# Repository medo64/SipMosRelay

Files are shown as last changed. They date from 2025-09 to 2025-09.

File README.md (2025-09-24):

SIP MOS Relay
-------------

High-voltage MOSFET-based switch in PhotoMOS footprint.

| Parameter | Min | Nom | Max |
|---|---:|---:|---:|
| Load voltage | 8 V | | 60 V |
| Continous load current | | | 6 A |
| Peak load current | | | 11 A |
| Power dissipation | | | 2 W |
| On-resistance | | 11.2 mΩ | 14.3 mΩ |
| Control input current  | |  500 µA | |
| Control current | | | 2 mA |
| Thermal resistance | | | 89.2 °C/W |
| Operating temperature  |  -40 °C | | +85 °C |

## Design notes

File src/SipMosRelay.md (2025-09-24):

## AuxPower Hardware

### Properties

| | |
|---|---|
| Size | 20.2 x 10.0 mm ~ 0.4 sqin |

### Parts

|  # | Part name | RefDes | Source |
|---:|---|---|---|
|  1 | D Zener 12V 0.5W [BZT52C12] (SOD123F) | D1 | 4878-BZT52C12DKR-ND |
|  1 | J Header (2w) | J1 | |
|  1 | J Header (3w) | J2 | |
|  1 | Q Transistor NPN 100 mA 65V [BC846B,235] (SOT23-3) | Q1 | 1727-1876-1-ND |
|  1 | Q MOSFET P 11A 60V ±20Vgs [RS3L110ATTB1] (SO-8) | Q2 | 846-RS3L110ATTB1CT-ND |
|  1 | R 10K 0.125W (0805) | R1 | RMCF0805FT10K0CT-ND |
|  2 | R 33K 0.125W (0805) | R2 | RMCF0805FT33K0CT-ND |
|  3 | R 47K 0.125W (0805) | R3 | RMCF0805FT47K0CT-ND |

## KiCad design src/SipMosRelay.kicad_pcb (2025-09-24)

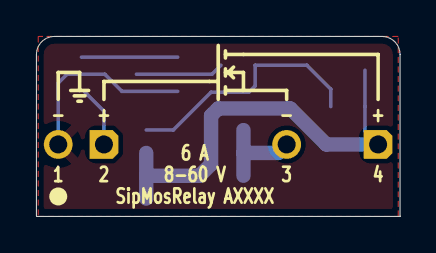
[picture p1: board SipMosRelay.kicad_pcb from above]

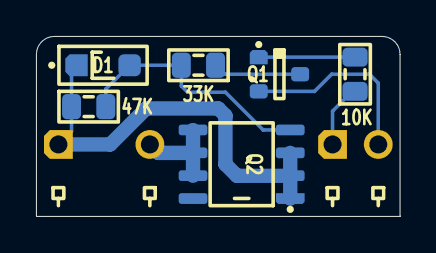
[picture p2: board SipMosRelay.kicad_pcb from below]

Board: 2 copper layers, 20.2 x 10.0 mm, 8 parts (8 on the bottom side), 7 nets.

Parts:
D1: BZT52C12; D Zener (SOD123FL)
J1: J Header (2w)
J2: J Header (3-2w)
Q1: BC846B,235; Q Transistor NPN (SOT23-3)
Q2: RS3L110ATTB1; Q MOSFET-P (SO-8)
R1: 10K; R (0805)
R2: 33K; R (0805)
R3: 47K; R (0805)

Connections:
BASE: Q1.1, R1.2
COLLECTOR: Q1.3, R2.1
CONTROL: J1.1, R1.1
GATE: D1.2, Q2.4, R2.2, R3.2
GND: J1.2, Q1.2
INPUT: D1.1, J2.1, Q2.1, Q2.2, Q2.3, R3.1
OUTPUT: J2.3, Q2.5, Q2.6, Q2.7
